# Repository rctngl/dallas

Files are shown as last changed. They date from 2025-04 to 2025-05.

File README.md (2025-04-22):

# Project Dallas

## Overview

> Project is in EARLY but active development. All hardware and firmware here is not tested yet.

The goal of this project is to apply a reasonably precise load of 0-20A to 20V DC power source. 

### Goals
- Dump 20A of 20V load (Active cooling?)
- Set the target current limit on the fly
- Display target and real current measurements on display
- Be powered with USB-C
- Use standard hardware where possible
- Programmable with Arduino
- Reasonably cost effective

## Development Flow

Each major working build will be created in its own `branch` and then merged into `master` when it becomes the active version.

## Open Source Notes

This is our first open source project and this will be built in the open so please keep that in mind when creating issues or making comments. 

We just want to build cool stuff for everyone to use!

## About the name, Dallas

All Rectangle projects use a location-based codename. 'Dallas' comes from the birthplace of American inventor and engineer [Otis Frank Boykin](https://en.wikipedia.org/wiki/Otis_Boykin), known for his work on the [precision wire resistor](https://www.invent.org/inductees/otis-boykin)... hence seemed fitting for our 'resistive load dump' project.

## About Rectangle Tool Co

We're a very small Australian company building tools for Automotive Electricians and electronics enthusiasts.

You can learn more on the (in progress) [website](https://rctngl.au) and following us on [Bluesky](https://bsky.app/profile/rctngl.au)

## Licence

The software and firmware in this project is licensed under the [MIT License](LICENSE-MIT).

The hardware is licensed under the [CERN Open Hardware Licence Version 2 - Permissive](LICENCE-CERN-OHL-P-v2).

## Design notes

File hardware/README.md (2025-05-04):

# Project Dallas - System Design

## Description

Project Dallas is a constant current electronic load for testing DC power sources in the automotive realm (12-24V) using Mosfets instead of resistive loads.

## Core Requirements

- **Load Voltage:** 12-30V
- **Load Current:** Up to 20A - Asking too much?
- **Load Wattage:** 600W Max (30V 20A)
- **Input Voltage**: ~9V (USB-C)

## Inspiration

The following projects were the original inspiration for the project and share similar frames of mind...

- [EEVBlog DC Load](https://www.youtube.com/watch?v=8xX2SVcItOA)
- [Scullcom DC Electronic Load](http://www.scullcom.uk/design-build-an-electronic-dc-load-part-1/)

Some additional projects are resources being used for the initial design...

- [Improved EEVBlog DC Load](https://www.reddit.com/r/electronics/comments/m9g10w/guide_improving_the_eevblog_diy_electronic_load/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)

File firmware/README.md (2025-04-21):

# Project Dallas - Firmware

## Overview

All Arduino code resides here. Currently the MCU is an ESP32S3. Further instructions to follow.

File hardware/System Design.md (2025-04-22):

# System Design

## Core Specifications

- **Input Voltage:** 12-20V
- **Output Current:** Up to 20A
- **Output Volttage:** Regulated via Current Loop (Load Dependent)
- **Current setpoint:** Controlled by ESP32

## Core Design

A majority of this design is based on the LM5145EVM-HD-20A [Evaluation Board](https://www.ti.com/tool/LM5145EVM-HD-20A) but with the following core changes:
- Single sided PCB with less space constraints
- Wider output voltage (~20V instead of 5V)
- MCU Controlled current limit

## Bill of Materials

### Control and Feedback

Ref | Part | Value | Mouser | Datasheet
|--|---|---|---|---|
| U1 | LM5145RGYR | Sync Buck Controller | [595-LM5145RGYR](https://au.mouser.com/ProductDetail/Texas-Instruments/LM5145RGYR?qs=gt1LBUVyoHkKVoSLabi7ZQ%3D%3D) | [Link](https://www.ti.com/lit/gpn/lm5145)

### Power Stage

Ref | Part | Value | Mouser | Datasheet
|--|---|---|---|---|
| Q1 | BSC117N08NS5ATMA1 | 80V **49A** N-CH | [726-BSC117N08NS5ATMA](https://au.mouser.com/ProductDetail/Infineon-Technologies/BSC117N08NS5ATMA1) | [Link](https://au.mouser.com/datasheet/2/196/Infineon_BSC117N08NS5_DataSheet_v02_01_EN-3360867.pdf)
| Q2 | BSC037N08NS5ATMA1 | 80V **100A** N-CH | [726-BSC037N08NS5ATMA](https://au.mouser.com/ProductDetail/Infineon-Technologies/BSC037N08NS5ATMA1) | [Link](https://au.mouser.com/datasheet/2/196/Infineon_BSC037N08NS5_DataSheet_v02_03_EN-3360724.pdf)
| L1 | SER2918H-103KL | 10uH 28A 2.86mOhm | [994-SER2918H-103KL](https://au.mouser.com/ProductDetail/Coilcraft/SER2918H-103KL) | [Link](https://au.mouser.com/datasheet/2/597/ser2900-270685.pdf)

#### Q1 and Q2 Mosfets
    These are the mosfets used in the Reference Design

In high current bucks, Q2 sees more abuse as Q1 only conducts during **ON Time**. Q2 conducts the full load when Q1 is off and is the current sink for the inductor. In case of a measurement overshoot and more working head room, a Q2 with more rated current is used.

Careful consideration for temp management as these FETS are at their temp limits when running 20A. 2oz copper and 4 layers should be used to manage heat. Potentially a fan?

#### L1 - Inductor
Reference design uses a 3.3uH inductor with an acceptable 22A Current and 40A Saturation current but would create apporx 1.5A current ripple. Need to lower this ripple as much as possible to clean up the `Rsense` voltage ripple into the OpAmp for tighter current loop control.

Inductor of at least 10uH required with 20A Constant and 30A Saturation Current Specs.

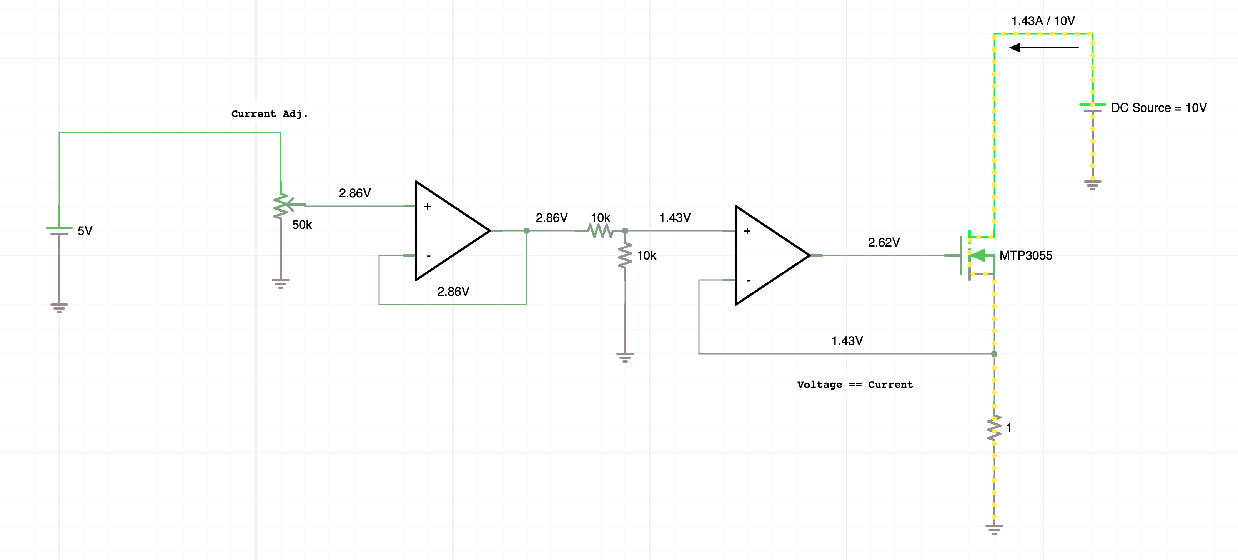
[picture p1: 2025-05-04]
hardware/simulation/eevblog-dc-load.png

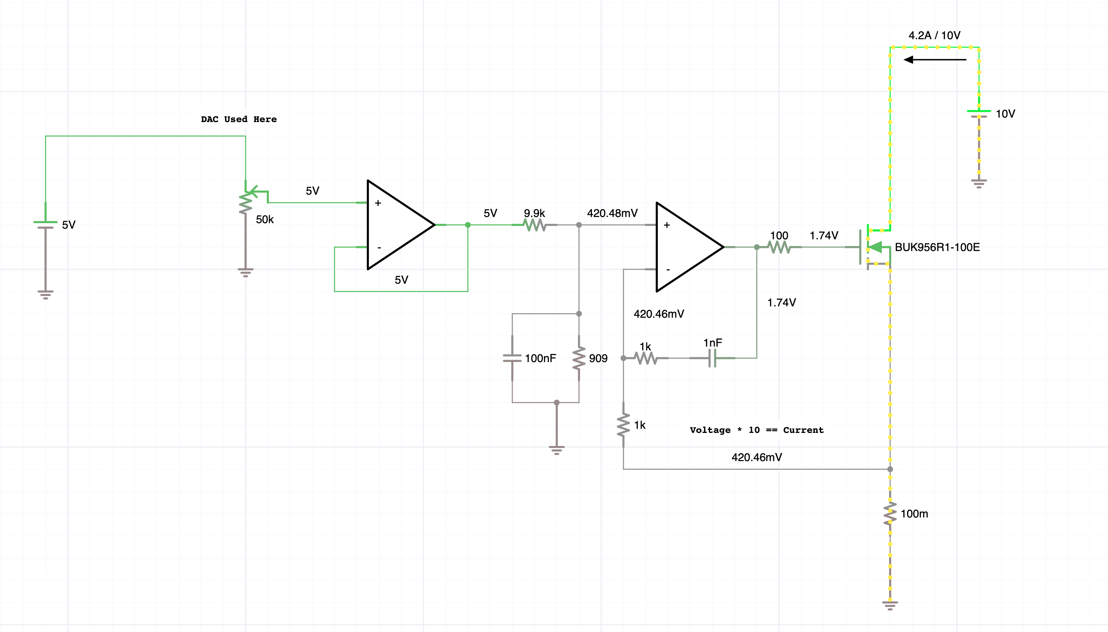
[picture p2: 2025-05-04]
hardware/simulation/scullcom-dc-v2.png

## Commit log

2025-04-22 Initial work porting the TI reference design
    [dallas-controller.kicad_pcb, dallas-controller.kicad_sch]
2025-05-04 Added basic EEVBlog Circuit Simulation
2025-05-04 Added basic Scullcom Circuit Simulation
